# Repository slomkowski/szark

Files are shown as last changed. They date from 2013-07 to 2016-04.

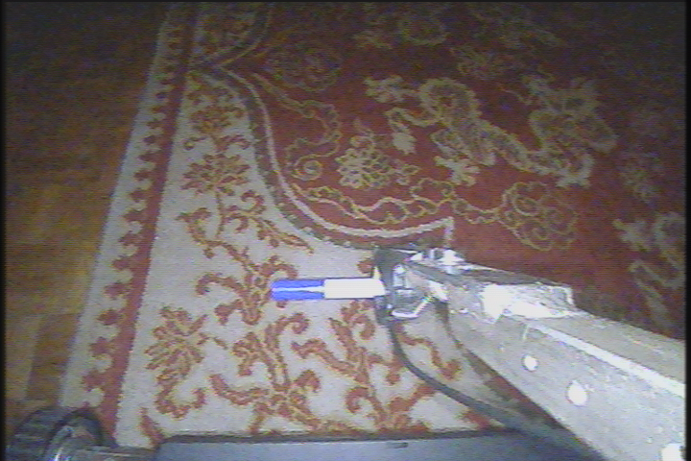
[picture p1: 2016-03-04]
server/camera_server/test_image.png

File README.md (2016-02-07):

# SZARK

Autonomic robot platform. Work in progress.

## Installation

Requred packages for Ubuntu:
```bash
apt-get install clang cmake git libboost-all-dev libjsoncpp-dev liblog4cpp5-dev libnl-genl-3-dev libnl-route-3-dev libopencv-dev libusb-1.0-0-dev libdw-dev 
```

Steps to clone the repository:
```bash
git clone https://github.com/slomkowski/szark.git
cd szark/
git submodule init
git submodule update
```

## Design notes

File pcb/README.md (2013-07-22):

SZARK - PCBs and schematics
===========================

&copy; 2011 - 2013 Michał Słomkowski GNU GPL v.3
https://github.com/slomkowski/szark

The files here are created in Cadsoft Eagle 6.x Light. You have to have this program installed to open them.

The project contains:
* **bridge** - interface between computer and other robot peripherals,
* **arm_driver**
* **motor_driver**
* **i2c_expander**
* **charger**
* **encoder**, **encoder_se**,**encoder_wrist** - various optical encoder designs installed on power motors and robotic arm.

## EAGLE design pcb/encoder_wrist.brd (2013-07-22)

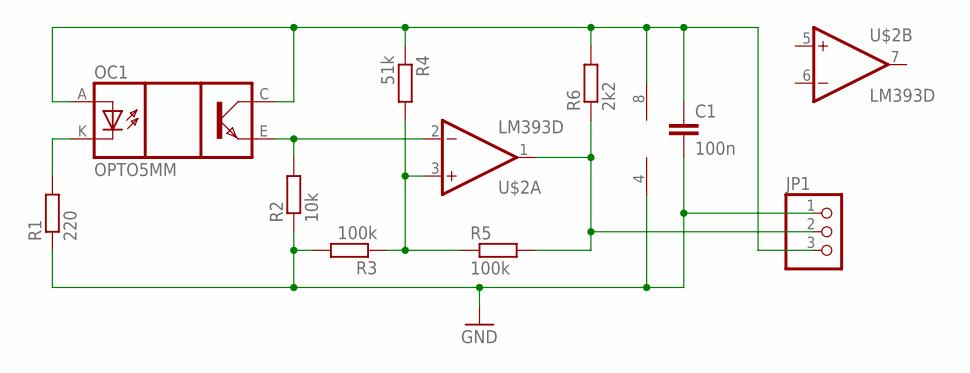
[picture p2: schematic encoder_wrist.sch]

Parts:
C1: 100n; C1206
JP1: PINHD-1X3/90; 1X03/90
OC1: OPTO5MM; OPTO_5MM
R1: 220; M1206
R2: 10k; M1206
R3, R5: 100k; M1206
R4: 51k; M1206
R6: 2k2; M1206
U$2: LM393D; SO08

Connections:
GND: C1.2, JP1.1, R1.1, R2.1, R3.2, U$2.4 (V-)
unnamed: OC1.K (C), R1.2
unnamed: R3.1, R4.2, R5.1, U$2.3 (+IN)
unnamed: JP1.2, R5.2, R6.1, U$2.1 (OUT)
unnamed: OC1.E (EMIT), R2.2, U$2.2 (-IN)
unnamed: C1.1, JP1.3, OC1.A, OC1.C (COL), R4.1, R6.2, U$2.8 (V+)

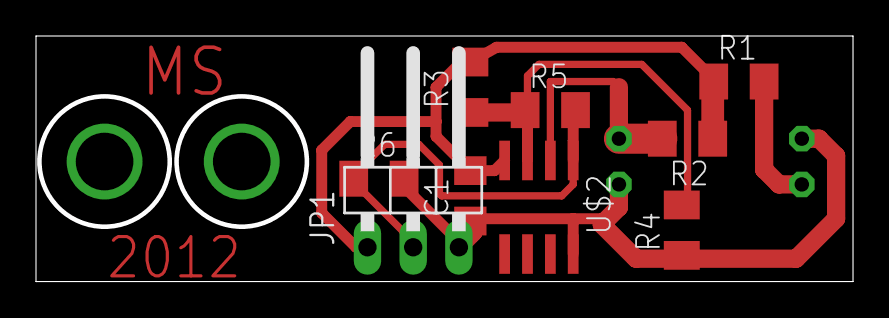
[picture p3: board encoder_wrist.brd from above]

Board: 2 copper layers, 45.4 x 13.6 mm, 10 parts (1 on the bottom side), 6 nets.

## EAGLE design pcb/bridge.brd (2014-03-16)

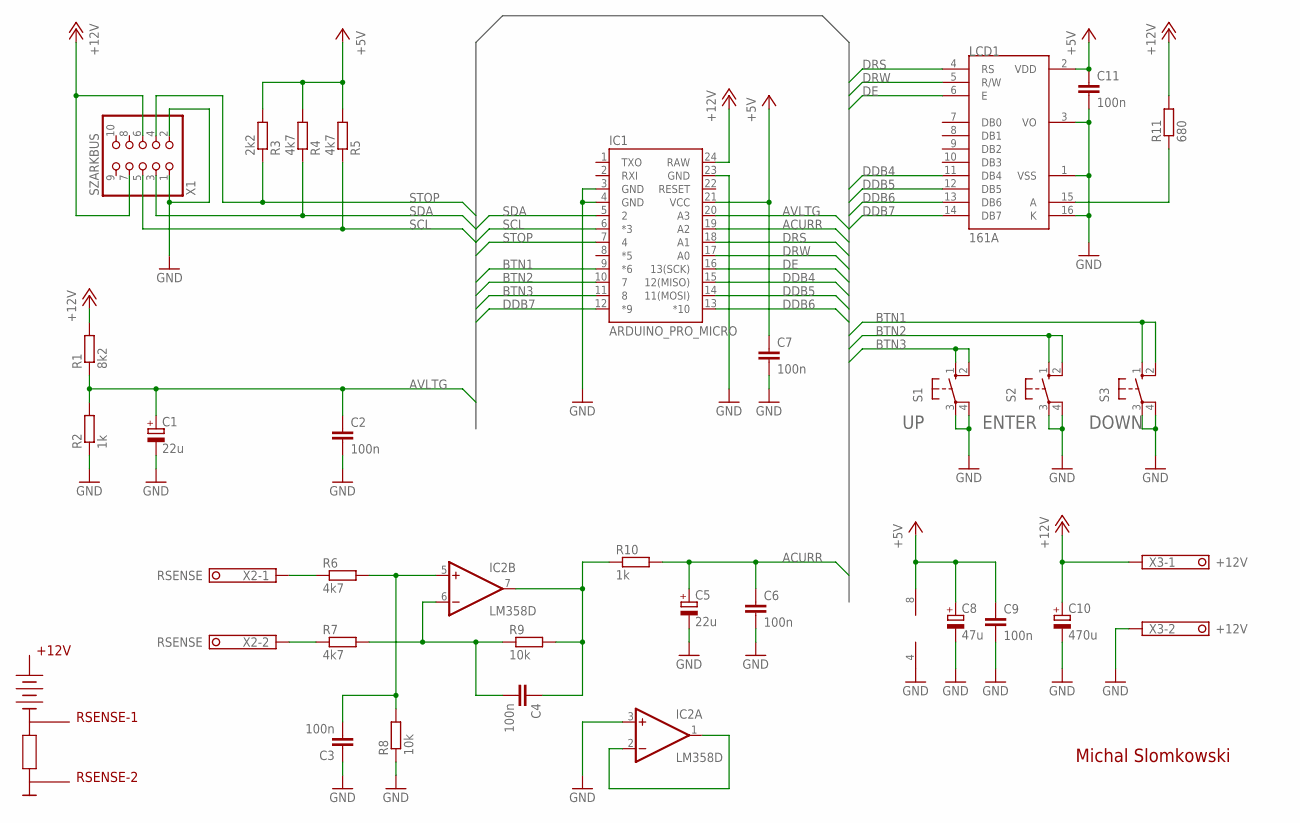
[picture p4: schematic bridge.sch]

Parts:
C1, C5: 22u; B/3528-21W
C2, C4, C6, C7, C9, C11: 100n; C1206
C3: 100n; C1210
C8: 47u; C/6032-28W
C10: 470u; E5-8,5
IC1: ARDUINO_PRO_MICRO
IC2: LM358D; SO08
LCD1: 161A
R1: 8k2; M1206
R2, R10: 1k; M1206
R3: 2k2; M1206
R4, R5, R6, R7: 4k7; M1206
R8, R9: 10k; M1206
R11: 680; 0207/12
S1, S2, S3: 10-XX; B3F-10XX
X1: SZARKBUS; 2X05
X2: RSENSE; 1751248
X3: +12V; 1751248

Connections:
+5V: C7.1, C8.+, C9.1, C11.1, IC1.21 (VCC), IC2.8 (V+), LCD1.2 (VDD), R3.2, R4.2, R5.2
+12V: C10.+, IC1.24 (RAW), R1.2, R11.2, X1.6, X1.7, X3.1
ACURR: C5.+, C6.1, IC1.19 (A2), R10.2
AVLTG: C1.+, C2.1, IC1.20 (A3), R1.1, R2.2
BTN1: IC1.9 (*6), S3.1 (S), S3.2 (S1)
BTN2: IC1.10 (7), S2.1 (S), S2.2 (S1)
BTN3: IC1.11 (8), S1.1 (S), S1.2 (S1)
DDB4: IC1.15 (12(MISO)), LCD1.11 (DB4)
DDB5: IC1.14 (11(MOSI)), LCD1.12 (DB5)
DDB6: IC1.13 (*10), LCD1.13 (DB6)
DDB7: IC1.12 (*9), LCD1.14 (DB7)
DE: IC1.16 (13(SCK)), LCD1.6 (E)
DRS: IC1.18 (A1), LCD1.4 (RS)
DRW: IC1.17 (A0), LCD1.5 (R/W)
GND: C1.-, C2.2, C3.1, C5.-, C6.2, C7.2, C8.-, C9.2, C10.-, C11.2, IC1.3 (GND), IC1.4 (GND), IC1.23 (GND), IC2.3 (+IN), IC2.4 (V-), LCD1.1 (VSS), LCD1.3 (VO), LCD1.16 (K), R2.1, R8.1, S1.3, S1.4 (P1), S2.3, S2.4 (P1), S3.3, S3.4 (P1), X1.1, X1.2, X3.2
unnamed: C3.2, IC2.5 (+IN), R6.2, R8.2
unnamed: LCD1.15 (A), R11.1
unnamed: C4.2, IC2.6 (-IN), R7.2, R9.1
unnamed: IC2.1 (OUT), IC2.2 (-IN)
unnamed: R7.1, X2.2
unnamed: R6.1, X2.1
NET3: C4.1, IC2.7 (OUT), R9.2, R10.1
SCL: IC1.6 (*3), R5.1, X1.5
SDA: IC1.5 (2), R4.1, X1.3
STOP: IC1.7 (4), R3.1, X1.4

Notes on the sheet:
+12V
RSENSE-1
RSENSE-2
ENTER
DOWN
Michal Slomkowski

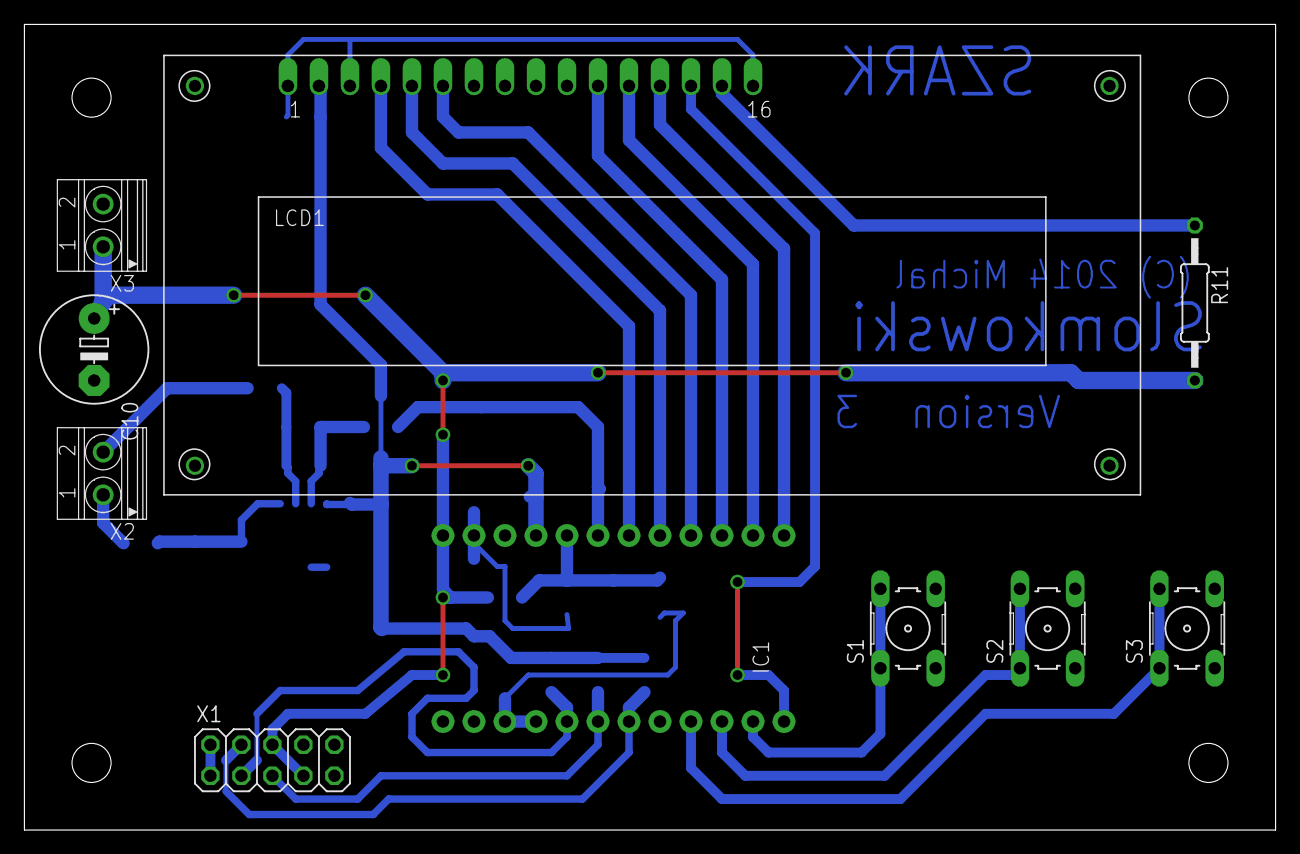
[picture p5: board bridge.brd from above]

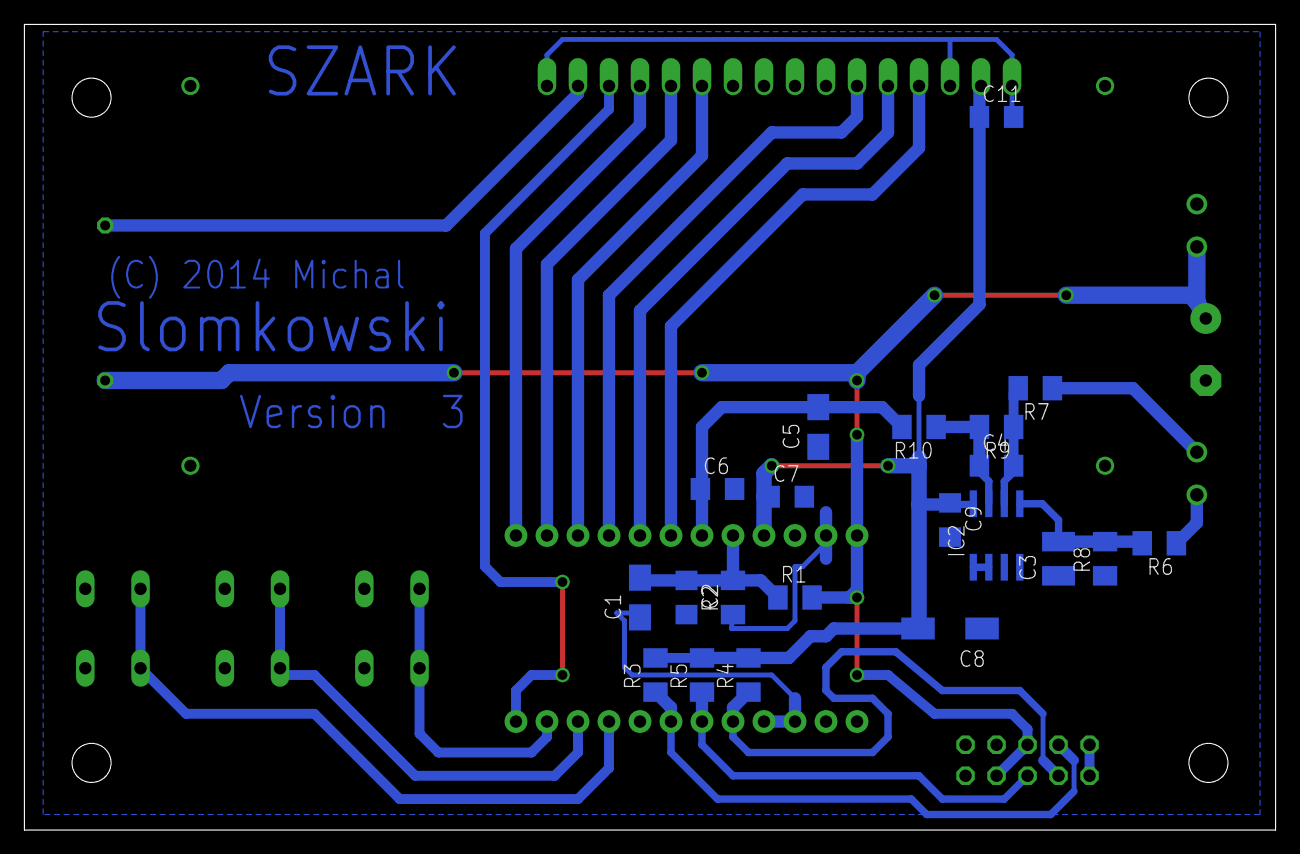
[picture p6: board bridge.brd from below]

Board: 2 copper layers, 102.5 x 66.0 mm, 31 parts (21 on the bottom side), 25 nets.

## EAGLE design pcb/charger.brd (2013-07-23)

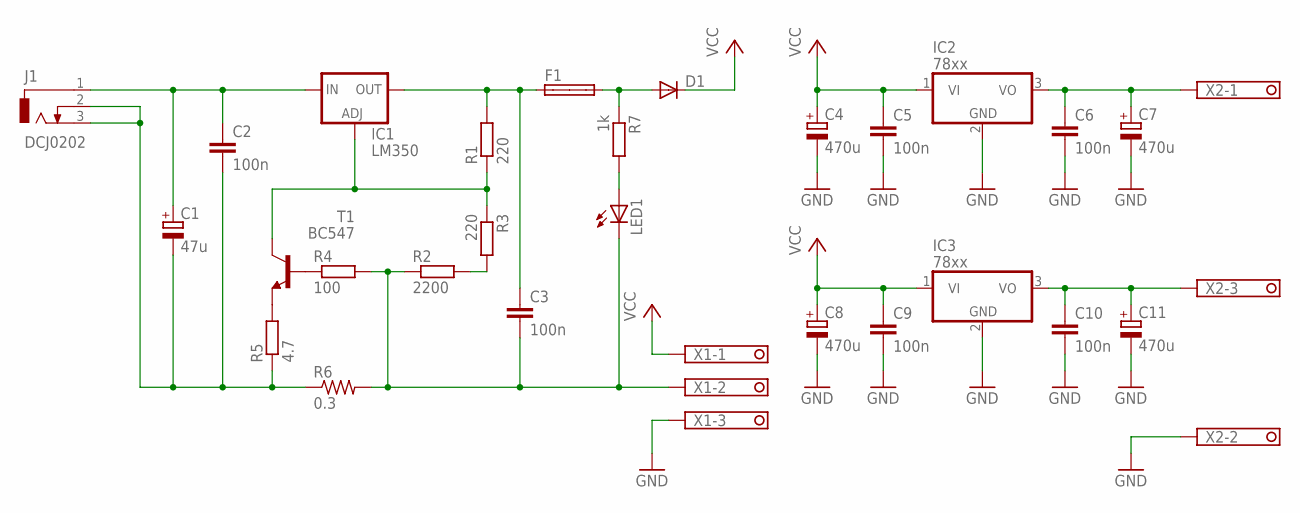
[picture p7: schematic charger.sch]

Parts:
C1: 47u; E2,5-7
C2, C3, C5, C6, C9, C10: 100n; C050-030X075
C4, C7, C8, C11: 470u; E5-10,5
D1: SB320; DO201-15
F1: SHK20L
IC1: LM350; 317TS
IC2, IC3: 78xx; TO220V
J1: DCJ0202
LED1: LED5MM
R1, R3: 220; 0207/10
R2: 2200; 0207/10
R4: 100; 0207/10
R5: 4.7; 0207/10
R6: 0.3; 0617/22
R7: 1k; 0207/10
T1: BC547; TO92
X1, X2: 1751251

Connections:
GND: C4.-, C5.2, C6.2, C7.-, C8.-, C9.2, C10.2, C11.-, IC2.2 (GND), IC3.2 (GND), X1.3, X2.2
unnamed: C1.+, C2.1, IC1.3 (IN), J1.1
unnamed: C1.-, C2.2, J1.2, J1.3, R5.1, R6.1
unnamed: R4.1, T1.2 (B)
unnamed: R2.2, R3.2
unnamed: IC1.1 (ADJ), R1.1, R3.1, T1.3 (C)
unnamed: C10.1, C11.+, IC3.3 (VO), X2.3
unnamed: C3.2, LED1.K (C), R2.1, R4.2, R6.2, X1.2
unnamed: R5.2, T1.1 (E)
unnamed: D1.A, F1.2A, R7.1
unnamed: LED1.A, R7.2
unnamed: C6.1, C7.+, IC2.3 (VO), X2.1
unnamed: C3.1, F1.1A, IC1.2 (OUT), R1.2
VCC: C4.+, C5.1, C8.+, C9.1, D1.C, IC2.1 (VI), IC3.1 (VI), X1.1

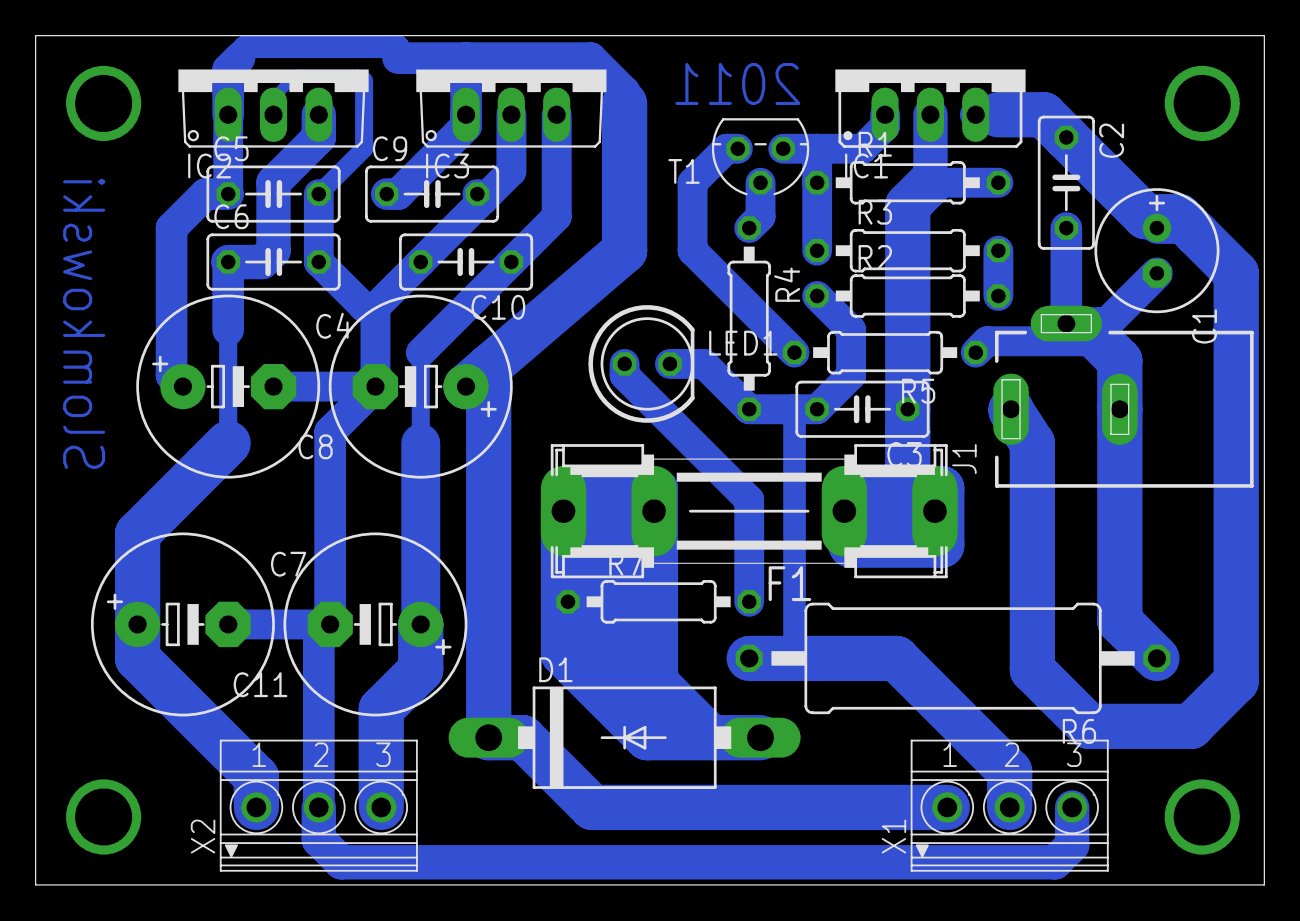
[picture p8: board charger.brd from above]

Board: 2 copper layers, 68.9 x 47.6 mm, 28 parts (0 on the bottom side), 14 nets.

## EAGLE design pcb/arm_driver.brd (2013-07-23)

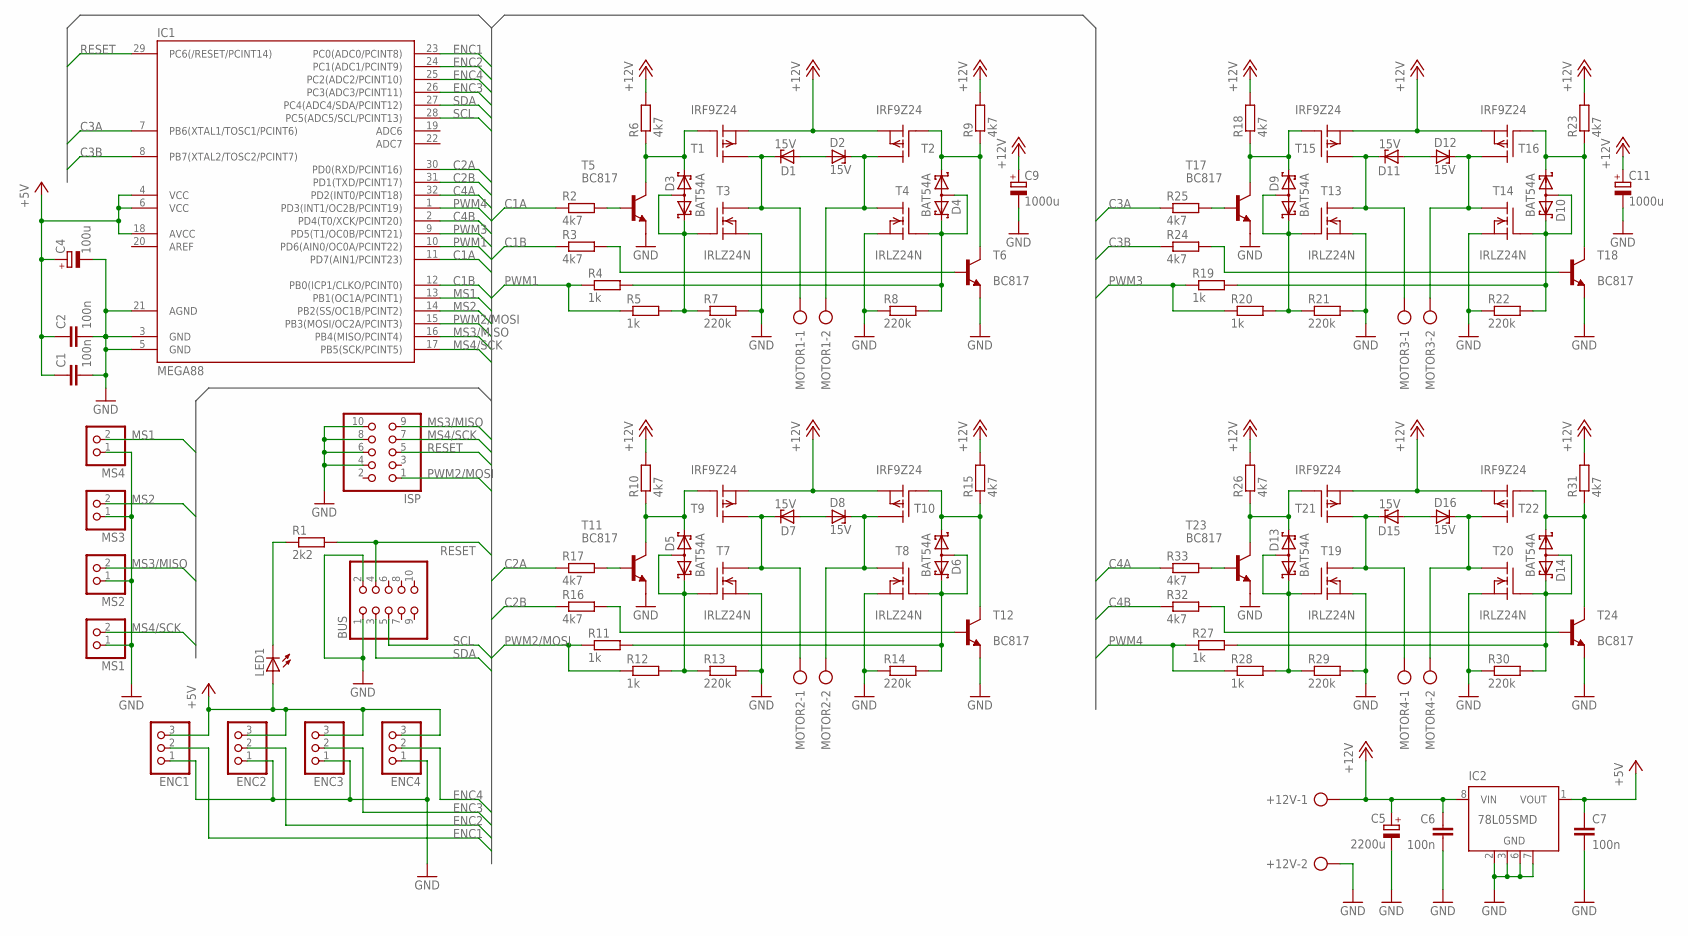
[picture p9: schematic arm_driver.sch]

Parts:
+12V: AK500/2
BUS: PINHD-2X5; 2X05
C1, C2, C6, C7: 100n; C1206
C4: 100u; D/7343-31R
C5: 2200u; E7,5-16
C9, C11: 1000u; E5-13
D1, D2, D7, D8, D11, D12, D15, D16: 15V; SOD80C
D3, D4, D5, D6, D9, D10, D13, D14: BAT54A; SOT23
ENC1, ENC2, ENC3, ENC4: PINHD-1X3; 1X03
IC1: MEGA88; TQFP32-08
IC2: 78L05SMD; SO08
ISP: PINHD-2X5; 2X05
LED1: LEDKA-3528ASYC; KA-3528ASYC
MOTOR1, MOTOR2, MOTOR3, MOTOR4: AK500/2
MS1, MS2, MS3, MS4: PINHD-1X2; 1X02
R1: 2k2; R1206
R2, R3, R6, R9, R10, R15, R16, R17, R18, R23, R24, R25, R26, R31, R32, R33: 4k7; R1206
R4, R5, R11, R12, R19, R20, R27, R28: 1k; R1206
R7, R8, R13, R14, R21, R22, R29, R30: 220k; R1206
T1, T2, T9, T10, T15, T16, T21, T22: IRF9Z24; TO220
T3, T4, T7, T8, T13, T14, T19, T20: IRLZ24N; TO220
T5, T6, T11, T12, T17, T18, T23, T24: BC817; SOT23-BEC

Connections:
+5V: C1.1, C2.1, C4.+, C7.1, ENC1.3, ENC2.3, ENC3.3, ENC4.3, IC1.4 (VCC), IC1.6 (VCC), IC1.18 (AVCC), IC2.1 (VOUT), LED1.A
+12V: +12V.1, C5.+, C6.1, C9.+, C11.+, IC2.8 (VIN), R6.2, R9.2, R10.2, R15.2, R18.2, R23.2, R26.2, R31.2, T1.3 (S), T2.3 (S), T9.3 (S), T10.3 (S), T15.3 (S), T16.3 (S), T21.3 (S), T22.3 (S)
C1A: IC1.11 (PD7(AIN1/PCINT23)), R2.1
C1B: IC1.12 (PB0(ICP1/CLKO/PCINT0)), R3.1
C2A: IC1.30 (PD0(RXD/PCINT16)), R17.1
C2B: IC1.31 (PD1(TXD/PCINT17)), R16.1
C3A: IC1.7 (PB6(XTAL1/TOSC1/PCINT6)), R25.1
C3B: IC1.8 (PB7(XTAL2/TOSC2/PCINT7)), R24.1
C4A: IC1.32 (PD2(INT0/PCINT18)), R33.1
C4B: IC1.2 (PD4(T0/XCK/PCINT20)), R32.1
ENC1: ENC1.2, IC1.23 (PC0(ADC0/PCINT8))
ENC2: ENC2.2, IC1.24 (PC1(ADC1/PCINT9))
ENC3: ENC3.2, IC1.26 (PC3(ADC3/PCINT11))
ENC4: ENC4.2, IC1.25 (PC2(ADC2/PCINT10))
GND: +12V.2, BUS.1, BUS.2, C1.2, C2.2, C4.-, C5.-, C6.2, C7.2, C9.-, C11.-, ENC1.1, ENC2.1, ENC3.1, ENC4.1, IC1.3 (GND), IC1.5 (GND), IC1.21 (AGND), IC2.2 (GND), IC2.3 (GND), IC2.6 (GND), IC2.7 (GND), ISP.4, ISP.6, ISP.8, ISP.10, MS1.1, MS2.1, MS3.1, MS4.1, R7.2, R8.1, R13.2, R14.1, R21.2, R22.1, R29.2, R30.1, T3.3 (S), T4.3 (S), T5.E, T6.E, T7.3 (S), T8.3 (S), T11.E, T12.E, T13.3 (S), T14.3 (S), T17.E, T18.E, T19.3 (S), T20.3 (S), T23.E, T24.E
MS1: IC1.13 (PB1(OC1A/PCINT1)), MS4.2
MS2: IC1.14 (PB2(SS/OC1B/PCINT2)), MS3.2
MS3/MISO: IC1.16 (PB4(MISO/PCINT4)), ISP.9, MS2.2
MS4/SCK: IC1.17 (PB5(SCK/PCINT5)), ISP.7, MS1.2
unnamed: LED1.C, R1.1
unnamed: D2.C, MOTOR1.2, T2.2 (D), T4.2 (D)
unnamed: D1.A, D2.A
unnamed: D3.2 (K2), R6.1, T1.1 (G), T5.C
unnamed: D4.1 (K1), R9.1, T2.1 (G), T6.C
unnamed: D4.2 (K2), D4.3 (AA), R4.2, R8.2, T4.1 (G)
unnamed: R3.2, T6.B
unnamed: R2.2, T5.B
unnamed: D3.1 (K1), D3.3 (AA), R5.2, R7.1, T3.1 (G)
unnamed: D1.C, MOTOR1.1, T1.2 (D), T3.2 (D)
unnamed: D7.C, MOTOR2.1, T7.2 (D), T9.2 (D)
unnamed: D8.C, MOTOR2.2, T8.2 (D), T10.2 (D)
unnamed: D5.2 (K2), R10.1, T9.1 (G), T11.C
unnamed: D6.1 (K1), R15.1, T10.1 (G), T12.C
unnamed: D6.2 (K2), D6.3 (AA), R11.2, R14.2, T8.1 (G)
unnamed: D5.1 (K1), D5.3 (AA), R12.2, R13.1, T7.1 (G)
unnamed: D7.A, D8.A
unnamed: R16.2, T12.B
unnamed: R17.2, T11.B
unnamed: D11.C, MOTOR3.1, T13.2 (D), T15.2 (D)
unnamed: D12.C, MOTOR3.2, T14.2 (D), T16.2 (D)
unnamed: D9.2 (K2), R18.1, T15.1 (G), T17.C
unnamed: D10.1 (K1), R23.1, T16.1 (G), T18.C
unnamed: D10.2 (K2), D10.3 (AA), R19.2, R22.2, T14.1 (G)
unnamed: D9.1 (K1), D9.3 (AA), R20.2, R21.1, T13.1 (G)
unnamed: D11.A, D12.A
unnamed: R24.2, T18.B
unnamed: R25.2, T17.B
unnamed: D15.C, MOTOR4.1, T19.2 (D), T21.2 (D)
unnamed: D16.C, MOTOR4.2, T20.2 (D), T22.2 (D)
unnamed: D13.2 (K2), R26.1, T21.1 (G), T23.C
unnamed: D14.1 (K1), R31.1, T22.1 (G), T24.C
unnamed: D14.2 (K2), D14.3 (AA), R27.2, R30.2, T20.1 (G)
unnamed: D13.1 (K1), D13.3 (AA), R28.2, R29.1, T19.1 (G)
unnamed: D15.A, D16.A
unnamed: R32.2, T24.B
unnamed: R33.2, T23.B
PWM1: IC1.10 (PD6(AIN0/OC0A/PCINT22)), R4.1, R5.1
PWM2/MOSI: IC1.15 (PB3(MOSI/OC2A/PCINT3)), ISP.1, R11.1, R12.1
PWM3: IC1.9 (PD5(T1/OC0B/PCINT21)), R19.1, R20.1
PWM4: IC1.1 (PD3(INT1/OC2B/PCINT19)), R27.1, R28.1
RESET: BUS.4, IC1.29 (PC6(/RESET/PCINT14)), ISP.5, R1.2
SCL: BUS.5, IC1.28 (PC5(ADC5/SCL/PCINT13))
SDA: BUS.3, IC1.27 (PC4(ADC4/SDA/PCINT12))

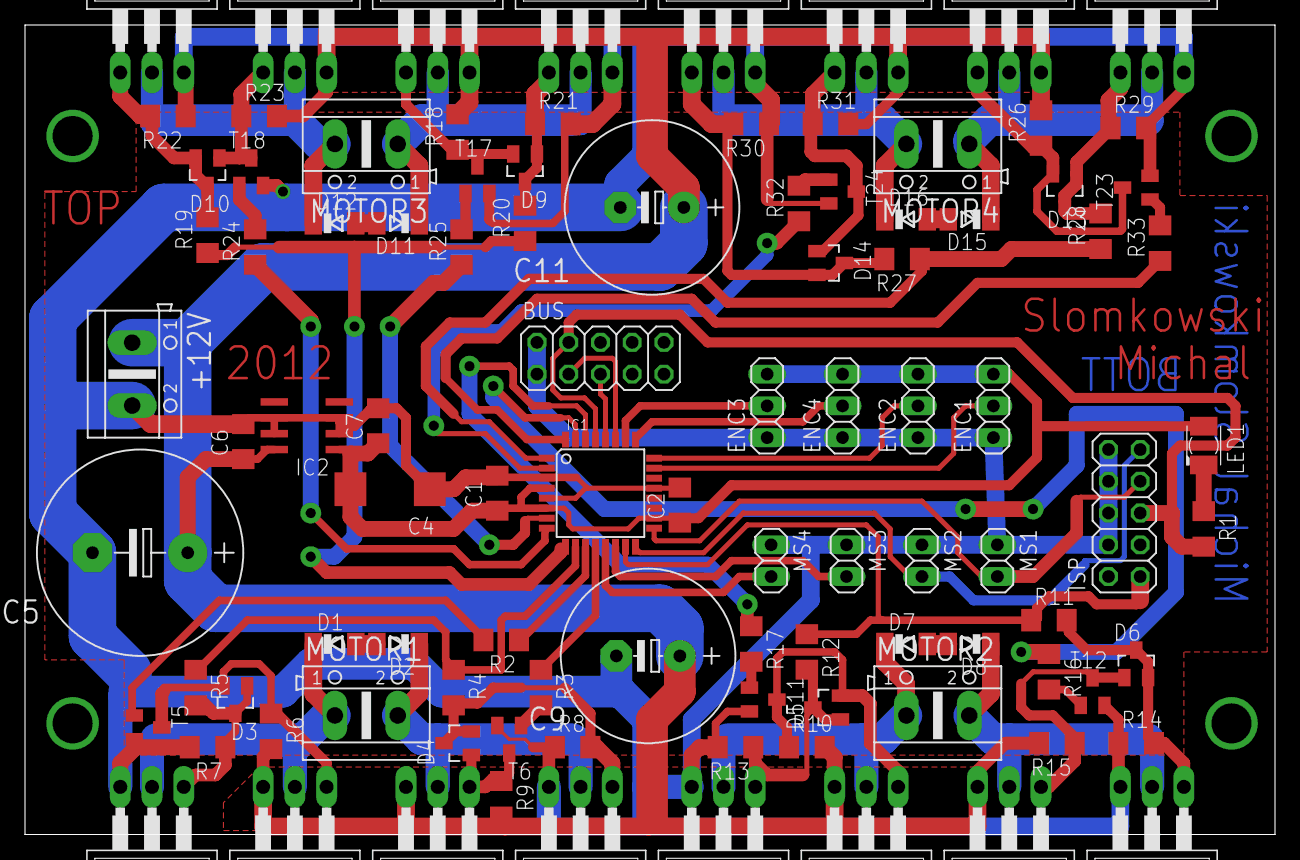
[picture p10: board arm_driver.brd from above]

Board: 2 copper layers, 100.0 x 64.8 mm, 99 parts (0 on the bottom side), 63 nets.

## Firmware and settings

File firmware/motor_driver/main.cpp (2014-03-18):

/*
 #  SZARK - Sterowana Zdalnie lub Autonomicznie Rozwojowa Konstrukcja
 #  Michał Słomkowski 2011
 #  www.flylab.ovh.org m.slomkowski@gmail.com
 */

// main module
#include "global.hpp"

#include <avr/io.h>
#include <avr/interrupt.h>
#include <avr/wdt.h>

#include "motor.hpp"
#include "i2c-slave.hpp"

int main() {
#if DEBUG
	// debug pin set to output
	DDR(DEBUG_PORT) |= (1 << DEBUG_PIN);
#endif

	motor::init();
	i2c_initialize((I2C_SLAVE_ADDRESS << 1));

	sei();

	// Watchdog
#if !DEBUG
	wdt_enable(WDTO_120MS);
#endif

	while (1) {
		// generic
		if (i2c_reply_ready()) {
			motor::Motor motor = (motor::Motor) i2c_wrbuf[1];

			if (i2c_wrbuf[0] == motor::GET_SPEED) {
				i2c_rdbuf[0] = motor::getSpeed(motor);
			} else {
				i2c_rdbuf[0] = motor::getDirection(motor);
			}

			i2c_reply_done(1);
		}

		if (i2c_message_ready()) {
			motor::Motor motor = (motor::Motor) i2c_wrbuf[1];

			switch (i2c_wrbuf[0]) {
			case motor::BRAKE:
				motor::setDirection(motor::MOTOR1, motor::STOP);
				motor::setDirection(motor::MOTOR2, motor::STOP);
				break;
			case motor::SET_SPEED:
				motor::setSpeed(motor, i2c_wrbuf[2]);
				break;
			case motor::SET_DIRECTION:
				motor::setDirection(motor, (motor::Direction) i2c_wrbuf[2]);
				break;

			};
			i2c_message_done();
		}

#if !DEBUG
		wdt_reset();
#endif
	}
}

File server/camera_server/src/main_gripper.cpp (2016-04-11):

#define BACKWARD_HAS_DW 1

#include "IoServiceProvider.hpp"
#include "initialization.hpp"

#include <backward.hpp>
#include <wallaroo/catalog.h>

using namespace std;
using namespace wallaroo;

int main(int argc, char *argv[]) {
    backward::SignalHandling sh;

    const char *banner = "SZARK Camera Server\n(C) Michał Słomkowski\nCompilation: " __DATE__;

    auto configFiles = common::init::initializeProgram(argc, argv, banner);

    Catalog c;
    c.Create("conf", "Configuration", configFiles);
    c.Create("imgGrabberLeft", "Video4LinuxImageGrabber", string("left"));
    c.Create("imgGrabberRight", "Video4LinuxImageGrabber", string("right"));
    c.Create("ifaceProvider", "InterfaceProvider", false);
    c.Create("imgCombiner", "GripperImageSource");
    c.Create("hudPainter", "GripperHudPainter");
    c.Create("ioServiceProvider", "IoServiceProvider");
    c.Create("srv", "NetworkServer");
    c.Create("jpegEncoder", "OpenCvJpegEncoder");

    wallaroo_within(c) {
        use("conf").as("config").of("imgGrabberLeft");
        use("conf").as("config").of("imgGrabberRight");
        use("conf").as("config").of("imgCombiner");
        use("conf").as("config").of("hudPainter");
        use("conf").as("config").of("srv");

        use("ioServiceProvider").as("ioServiceProvider").of("srv");
        use("imgGrabberLeft").as("leftCameraGrabber").of("imgCombiner");
        use("imgGrabberRight").as("rightCameraGrabber").of("imgCombiner");
        use("hudPainter").as("hudPainter").of("imgCombiner");
        use("imgCombiner").as("imageSource").of("srv");
        use("jpegEncoder").as("jpegEncoder").of("srv");
    };

    c.CheckWiring();
    c.Init();

    std::shared_ptr<common::IoServiceProvider>(c["ioServiceProvider"])->run();

    return 0;
}

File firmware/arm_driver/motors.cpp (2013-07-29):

#include "global.h"

#include <avr/io.h>
#include <inttypes.h>
#include <avr/interrupt.h>
#include <util/delay.h>

#include "motors.h"

// mode of operation - DIR, POS, CAL - global
volatile bool calibrated __attribute__ ((section (".noinit")));
volatile bool interruptCalibration, startCalibration;

#define getval(sfr, bit) (bit_is_set(sfr, bit) ? true : false)

// this struct stores the values for single joint
static volatile struct {
	// position
	POSITION currPos; // current position
	POSITION destPos; // desired position
	POSITION maxPos;  // maximal position

	// direction
	DIRECTION allowedDir;
	DIRECTION currDir;

	// speed
	SPEED currSpeed;
	SPEED initSpeed;

	// calibration
	bool calibrated;
	MODE mode;

	// MS parameters
	uint8_t msCounter;bool msCurrState; // false - low, true - high

	// encoders
	bool encoderState;bool prevEncoderState;
} joints[4] __attribute__ ((section (".noinit")));

// these values index the 'joints' table.
typedef enum {
	SHOULDER = 0, ELBOW, GRIPPER, WRIST
} JOINT_INDEX;

//*** local functions
static JOINT_INDEX toJoint(MOTOR motor);
static MOTOR toMotors(JOINT_INDEX index);
static MOTOR toMotors(uint8_t index);
static void setTimerMs(uint16_t interval); // in milliseconds
static void setTimerContinuous();
static bool getMsState(JOINT_INDEX index);
static bool getMsState(uint8_t index);

static volatile bool timerNotClear = true, timerOneShot = true;

//*** basic getters

SPEED motor_get_speed(MOTOR motor) {
	return joints[toJoint(motor)].currSpeed;
}

DIRECTION motor_get_direction(MOTOR motor) {
	return joints[toJoint(motor)].currDir;
}

POSITION motor_get_position(MOTOR motor) {
	return joints[toJoint(motor)].currPos;
}

MODE motor_get_mode(MOTOR motor) {
	return joints[toJoint(motor)].mode;
}

// basic setters. The setters put the data in the structure and send the data to the appropriate output (registers, pins)

void motor_set_speed(MOTOR motor, SPEED speed) {
	// put data to the struct
	joints[toJoint(motor)].currSpeed = speed;

	// put it to the registers
	switch (motor) {
	case MOTOR_SHOULDER:
		PWM_SHOULDER_REG = speed << 4;
		break;
	case MOTOR_ELBOW:
		PWM_ELBOW_REG = speed << 4;
		break;
	case MOTOR_WRIST:
		PWM_WRIST_REG = speed << 4;
		break;
	case MOTOR_GRIPPER:
		PWM_GRIPPER_REG = speed << 4;
		break;
	};
}

void motor_set_direction(MOTOR motor, DIRECTION direction) {
	DIRECTION currentDir;
	const JOINT_INDEX idx = toJoint(motor);

	if (joints[idx].mode == POS) joints[idx].mode = DIR;

	// put data to the struct, checking if the command is
	if ((((direction == MOTOR_FORWARD) || (direction == MOTOR_BACKWARD)) && (joints[idx].allowedDir == MOTOR_NONE)
		|| (joints[idx].allowedDir == direction))) joints[idx].currDir = direction;

	else joints[idx].currDir = MOTOR_STOP;

	currentDir = joints[idx].currDir;

	// put them to the output
	switch (motor) {
	case MOTOR_SHOULDER:
		if (currentDir == MOTOR_FORWARD) {
			PORT(MOTOR_SHOULDER_FORWARD_PORT) |= (1 << MOTOR_SHOULDER_FORWARD_PIN);
			PORT(MOTOR_SHOULDER_BACKWARD_PORT) &= ~(1 << MOTOR_SHOULDER_BACKWARD_PIN);
		} else if (currentDir == MOTOR_BACKWARD) {
			PORT(MOTOR_SHOULDER_FORWARD_PORT) &= ~(1 << MOTOR_SHOULDER_FORWARD_PIN);
			PORT(MOTOR_SHOULDER_BACKWARD_PORT) |= (1 << MOTOR_SHOULDER_BACKWARD_PIN);
		} else {
			// braking
			PORT(MOTOR_SHOULDER_FORWARD_PORT) |= (1 << MOTOR_SHOULDER_FORWARD_PIN);
			PORT(MOTOR_SHOULDER_BACKWARD_PORT) |= (1 << MOTOR_SHOULDER_BACKWARD_PIN);
		}
		break;
	case MOTOR_ELBOW:
		if (currentDir == MOTOR_FORWARD) {
			PORT(MOTOR_ELBOW_FORWARD_PORT) |= (1 << MOTOR_ELBOW_FORWARD_PIN);
			PORT(MOTOR_ELBOW_BACKWARD_PORT) &= ~(1 << MOTOR_ELBOW_BACKWARD_PIN);

		} else if (currentDir == MOTOR_BACKWARD) {
			PORT(MOTOR_ELBOW_FORWARD_PORT) &= ~(1 << MOTOR_ELBOW_FORWARD_PIN);
			PORT(MOTOR_ELBOW_BACKWARD_PORT) |= (1 << MOTOR_ELBOW_BACKWARD_PIN);
		} else {
			PORT(MOTOR_ELBOW_FORWARD_PORT) |= (1 << MOTOR_ELBOW_FORWARD_PIN);
			PORT(MOTOR_ELBOW_BACKWARD_PORT) |= (1 << MOTOR_ELBOW_BACKWARD_PIN);
		}
		break;
	case MOTOR_WRIST:
		if (currentDir == MOTOR_FORWARD) {
			PORT(MOTOR_WRIST_FORWARD_PORT) |= (1 << MOTOR_WRIST_FORWARD_PIN);
			PORT(MOTOR_WRIST_BACKWARD_PORT) &= ~(1 << MOTOR_WRIST_BACKWARD_PIN);

		} else if (currentDir == MOTOR_BACKWARD) {
			PORT(MOTOR_WRIST_FORWARD_PORT) &= ~(1 << MOTOR_WRIST_FORWARD_PIN);
			PORT(MOTOR_WRIST_BACKWARD_PORT) |= (1 << MOTOR_WRIST_BACKWARD_PIN);
		} else {
			PORT(MOTOR_WRIST_FORWARD_PORT) |= (1 << MOTOR_WRIST_FORWARD_PIN);
			PORT(MOTOR_WRIST_BACKWARD_PORT) |= (1 << MOTOR_WRIST_BACKWARD_PIN);
		}
		break;
	case MOTOR_GRIPPER:
		if (currentDir == MOTOR_FORWARD) {
			PORT(MOTOR_GRIPPER_FORWARD_PORT) |= (1 << MOTOR_GRIPPER_FORWARD_PIN);
			PORT(MOTOR_GRIPPER_BACKWARD_PORT) &= ~(1 << MOTOR_GRIPPER_BACKWARD_PIN);

		} else if (currentDir == MOTOR_BACKWARD) {
			PORT(MOTOR_GRIPPER_FORWARD_PORT) &= ~(1 << MOTOR_GRIPPER_FORWARD_PIN);
			PORT(MOTOR_GRIPPER_BACKWARD_PORT) |= (1 << MOTOR_GRIPPER_BACKWARD_PIN);
		} else {
			PORT(MOTOR_GRIPPER_FORWARD_PORT) |= (1 << MOTOR_GRIPPER_FORWARD_PIN);
			PORT(MOTOR_GRIPPER_BACKWARD_PORT) |= (1 << MOTOR_GRIPPER_BACKWARD_PIN);
		}
		break;
	};
}

void motor_set_position(MOTOR motor, POSITION position) {
	const JOINT_INDEX idx = toJoint(motor);

	if (joints[idx].calibrated == false) return;
	if (joints[idx].maxPos < position) return;

	if ((idx == GRIPPER) && (position > 0)) position = joints[GRIPPER].maxPos;

	joints[idx].destPos = position;

	if (joints[idx].currPos < position) {
		motor_set_direction(motor, MOTOR_FORWARD);
		joints[idx].mode = POS;
	} else if (joints[idx].currPos > position) {
		motor_set_direction(motor, MOTOR_BACKWARD);
		joints[idx].mode = POS;
	} else // if equal
	{
		motor_set_direction(motor, MOTOR_STOP);
		joints[idx].mode = DIR;
	}
}

void motor_brake() {
	uint8_t i;
	// instantly brake all the motors
	for (i = 0; i < 4; i++) {
		motor_set_speed(toMotors(i), 0);
		motor_set_direction(toMotors(i), MOTOR_STOP);
	}
}

//*** init functions
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

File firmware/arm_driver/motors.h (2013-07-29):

#ifndef _MOTORS_H_
#define _MOTORS_H_

#include <inttypes.h>

#include "global.h"
#include "arm_driver-commands.h"


//*** I/O configuration - bound to hardware

// output pins
#define MOTOR_GRIPPER_PWM_PORT D
#define MOTOR_GRIPPER_PWM_PIN 6
#define MOTOR_GRIPPER_FORWARD_PORT B
#define MOTOR_GRIPPER_FORWARD_PIN 0
#define MOTOR_GRIPPER_BACKWARD_PORT D
#define MOTOR_GRIPPER_BACKWARD_PIN 7

#define MOTOR_SHOULDER_PWM_PORT B
#define MOTOR_SHOULDER_PWM_PIN 3
#define MOTOR_SHOULDER_FORWARD_PORT D
#define MOTOR_SHOULDER_FORWARD_PIN 0
#define MOTOR_SHOULDER_BACKWARD_PORT D
#define MOTOR_SHOULDER_BACKWARD_PIN 1

#define MOTOR_WRIST_PWM_PORT D
#define MOTOR_WRIST_PWM_PIN 5
#define MOTOR_WRIST_FORWARD_PORT B
#define MOTOR_WRIST_FORWARD_PIN 6
#define MOTOR_WRIST_BACKWARD_PORT B
#define MOTOR_WRIST_BACKWARD_PIN 7

#define MOTOR_ELBOW_PWM_PORT D
#define MOTOR_ELBOW_PWM_PIN 3
#define MOTOR_ELBOW_FORWARD_PORT D
#define MOTOR_ELBOW_FORWARD_PIN 2
#define MOTOR_ELBOW_BACKWARD_PORT D
#define MOTOR_ELBOW_BACKWARD_PIN 4

#define PWM_GRIPPER_REG OCR0A
#define PWM_WRIST_REG OCR0B
#define PWM_SHOULDER_REG OCR2A
#define PWM_ELBOW_REG  OCR2B

// sensors
#define SENSOR_SHOULDER_ENC_PORT C
#define SENSOR_SHOULDER_ENC_PIN 0
#define SENSOR_SHOULDER_MS_PORT B
#define SENSOR_SHOULDER_MS_PIN 5

#define SENSOR_ELBOW_ENC_PORT C
#define SENSOR_ELBOW_ENC_PIN 1
#define SENSOR_ELBOW_MS_PORT B
#define SENSOR_ELBOW_MS_PIN 4

#define SENSOR_WRIST_ENC_PORT C
#define SENSOR_WRIST_ENC_PIN 2
#define SENSOR_WRIST_MS_PORT B
#define SENSOR_WRIST_MS_PIN 2

#define SENSOR_GRIPPER_ENC_PORT C
#define SENSOR_GRIPPER_ENC_PIN 3
#define SENSOR_GRIPPER_MS_PORT B
#define SENSOR_GRIPPER_MS_PIN 1

#define ENCODERS_PCMSK PCMSK1
#define SHOULDER_ENC_PCINT PCINT8
#define ELBOW_ENC_PCINT PCINT9
#define WRIST_ENC_PCINT PCINT10
#define GRIPPER_ENC_PCINT PCINT11

#define MS_PCMSK PCMSK0
#define SHOULDER_MS_PCINT PCINT5
#define ELBOW_MS_PCINT PCINT4
#define WRIST_MS_PCINT PCINT2
#define GRIPPER_MS_PCINT PCINT1

#define ENCODERS_INTERRUPT PCINT1_vect
#define MS_INTERRUPT PCINT0_vect

//*** initial speed settings - range 0 - 15
#define CAL_SPEED_SHOULDER	220
#define CAL_SPEED_ELBOW		100
#define CAL_SPEED_WRIST		100
#define CAL_SPEED_GRIPPER	15

#define POS_MAX_SHOULDER	79
#define POS_MAX_ELBOW	105
#define POS_MAX_WRIST	95
#define POS_MAX_GRIPPER	255

#define MS_DEBOUNCE_TIME 10 // ms
#define TIMER_MS_INTERVAL 2 // ms

#define MS_DEBOUNCE_COUNTER (MS_DEBOUNCE_TIME / TIMER_MS_INTERVAL)

//*** type definitions
typedef uint8_t POSITION;
typedef uint8_t SPEED;
// typedef DIRECTION - definition is in command-chars.h

typedef enum { DIR = 'D', POS = 'P', CAL = 'C' } MODE;
extern volatile bool startCalibration;
extern volatile bool calibrated __attribute__ ((section (".noinit")));
extern volatile bool interruptCalibration;

//*** getters
SPEED motor_get_speed(MOTOR motor);
DIRECTION motor_get_direction(MOTOR motor);
POSITION motor_get_position(MOTOR motor);
MODE motor_get_mode(MOTOR motor);

//*** setters
void motor_set_speed(MOTOR motor, SPEED speed);
void motor_set_direction(MOTOR motor, DIRECTION direction);
void motor_set_position(MOTOR motor, POSITION position);

//*** additional functions
void motor_calibrate();
void motor_brake();
void motor_init();


#endif

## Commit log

2013-07-16 Motor driver project added.
2013-07-17 Arm driver: removed UART, formatted all code to K&R, extracted speed controller to controller.c, playing around with PID.
2013-07-18 Motor_driver converted to C++.
2013-07-21 Displaying speed in motor driver menu.
2013-07-21 Added average speed array to the motor_driver. Made PWM module more C++-like, grouped variables into struct.
2013-07-22 PCB boards and schematics upload.
    [arm_driver.brd, arm_driver.sch, bridge.brd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]
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2013-07-23 Added fixed drive to motor driver.
    [motor.cpp, motor.h]
2013-07-23 Bridge USB schematic.
    [arm_driver.brd, arm_driver.sch, bridge.brd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]
2013-07-28 Bridge board ready.
    [bridge.brd, bridge.sch]
2013-07-28 Changed bridge board.
    [bridge.brd, bridge.sch]
2013-07-29 Fix name 'callibrate' to 'calibrate'
    [main.cpp]
2013-07-30 Motor_driver created enums in common/motor_driver-commands.h
2013-07-30 Adjusted bridge to use new enum interface for motor and arm.
2013-07-30 Motor_driver fixed error with not working controller.
    [controller.cpp, motor.cpp]
2013-07-31 arm_driver increased calibrate speed for elbow.
2013-08-05 bridge: Added I2C driver and part of motor_driver.
2013-08-06 Added full interface to motor_driver.
2013-08-06 Added I2C expander interface.
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2013-08-07 Added battery monitor to menu.
2013-08-08 I2C expander menu support.
2013-08-08 Added kill switch support.
2013-08-08 Added actual speed display to motor driver menu.
2013-08-08 Changed namespaces 'arm_driver' to 'arm' and 'motor_driver' to 'motor'.
2013-08-08 Updated names from MOTOR_X to X.
2013-08-08 Showing position in arm menu. Menu completed except kill switch.
2013-08-09 Corrected bridge voltage divider to match the resistor values.
    [bridge.brd, bridge.sch]
2013-08-10 Changed op-amp resistors values on the bridge schematic and general clean-up.
    [bridge.brd, bridge.sch]
2013-08-10 Replaced all _delay_ms with custom functions in separate file. The new delay function calls usbPoll().
    [main.cpp]
2013-08-10 Added interrupt routine to kill switch to hold down active state and modified the operation to open collector mode.
2013-08-10 Added protection from hang when i2c device is not available. Still testing version.
2013-08-11 Fixed wrong interrupt number.
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2013-08-11 Moved all protocol definitions in arm from defines to enums.
2013-08-11 Replaced defines with enums in motor driver interface.
    [main.cpp, motor_driver.cpp]
2013-08-11 Added kill switch support to menu.
2013-08-11 Updated waiting times and replaced custom waiting functions with _delay_ms in initialization functions.
    [main.cpp]
2013-08-12 Replaced NULL with nullptr.
    [menu.cpp]
2013-08-13 Added option to read buttons state without debouncing (no delay).
2013-08-18 arm and motor get.
2013-08-21 Added DataHolder class to hold requests. Changed arm, expander and motor classes to hold the pointer to Interface in order to use Implementation struct. Added some crazy reference initialization list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
2013-08-21 Implemented motor interface setters.
2013-08-22 Added arm interface to host.
2013-08-22 Added motor set and arm set to bridge.
2013-08-22 Changed bridge arm and motor get requests to support only one motor/joint at time.
2013-08-24 Reenabled menu in bridge, added some code in usb request and kill switch.
2013-08-24 Bridge support interrupt transfer to host.
2013-08-24 Removed RawCommunicator, interrupt transfer from device.
2013-08-26 I2C timer - stopping counting after successful receivement.
2013-08-27 Fixed missing watchdog reset in arm driver.
    [joint.cpp, main.cpp]
2013-08-28 Changed fusebits to start immadently after activation (without 65 ms delay).
2014-03-04 Rename 'bridge' project. Create board for new bridge.
    [bridge-old.brd, bridge-old.sch]
2014-03-06 bridge: Schematic beta version.
    [bridge.brd, bridge.sch]
2014-03-07 bridge: Update schematic positions and numbering.
    [bridge.brd, bridge.sch]
2014-03-10 bridge: board shape.
    [bridge.brd]
2014-03-13 bridge: Mock PCB ready.
    [bridge.brd, bridge.sch]
2014-03-13 bridge: Board ready beta.
    [bridge.brd, bridge.sch]
2014-03-13 bridge: Connect unused op-amp to the ground.
    [bridge.brd, bridge.sch]
2014-03-16 bridge: Update resistor values.
    [bridge.brd, bridge.sch]
2014-03-17 bridge: Adjust firmware to run on the new board.
    Makefile adjusted to program with AVRDoper.
2014-03-17 Add Arduino Pro Micro schematic.
2014-03-17 Fix common header references from .h to .hpp
    [joint.cpp, joint.h, main.cpp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]
2014-03-17 bridge: Update battery voltage factor.
2014-03-18 Change .h to .hpp in arm_driver and motor_driver.
2014-03-18 bridge: Add software reset when UP+DOWN buttons.
    [main.cpp]
2014-03-18 bridge: Add LED support.
2014-03-22 Send packet with the fixed size of 128 bytes. Fast.
    [main.cpp]
2014-03-22 bridge: Add timeout to USB communication. The menu is disabled during USB communication. When it's severed, device informs about it on the display and reenables menu.
2014-03-22 bridge: Add reset device command.
    [usb-commands.hpp]
2014-04-06 Updated .gitignore and change permissions.
    [encoder.brd, encoder.sch, encoder_se.brd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]
2014-05-08 server: Fix NetServer sendersMap accesses to be thread-safe.
2014-05-11 server: Fix some logging messagess and remove dummy direction setting for motor in interface.
2014-05-13 server: Add removing commands to I2C devices when kill switch enabled.
2014-05-14 server: Fix loosing settings for motor (double command).
2014-05-14 server: Same fix for arm.
2014-09-24 arm: Remove support of wrist.
2014-09-26 client: Add support of kill switch.
2014-09-26 server: Remove wirst and update killswitch.
2014-09-28 client: Add new camera updater support.
2014-09-28 client: Add switching between cameras.
2014-09-28 client: Add switching between RAW and HUD modes.
2014-09-29 client: Add disabling camera when error occurred.
2014-09-29 client: Move control from Timer task to SwingWorker.
2014-09-29 client: Add independent camera and control error handling.
2014-10-01 client: Add timeouts to sockets and fix error with hanging.
2014-10-03 client: Add calibration support.
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2014-10-09 szarkcam: Add thread naming and reading resolution from config.
2014-10-11 server: Fix sending calibration request.
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2014-10-14 server: Fix resetting calibration status when kill switch during calibration.
2014-10-14 arm: Fix random data after calibration.
    [joint.cpp]
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2014-10-18 server: Fix tests to compile.
    [main.cpp]
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2015-12-08 common: Fix tests to make them compile.
    [main.cpp]
2015-12-08 camera: Fix tests to make them compile. Add head camera classes.
    [main.cpp, main_framegrabber.cpp]
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2015-12-08 camera: Reformat CMakeLists.txt to create static library.
    * reformat all code
    * clean up headers and header guards
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2015-12-10 camera: Add FPS info and unoptimized OpenCV warning.
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2015-12-13 camera: Fix and refactor frame grabber in V4L.
    [main_framegrabber.cpp]
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2015-12-19 common: Add prevention from sending commands to arm during calibration.
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2015-12-20 camera: Add motor speed bars to head HUD.
2016-01-05 camera: Set better struct initialization. common: Add better test for shared interface.
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2016-02-07 Fix many of the warnings indicated by ultra-pedantic mode.
    [main_framegrabber.cpp]
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2016-04-10 camera: Add flip/rotate support.
2016-04-11 camera: Add video input support and dynamic flip.
    [main_gripper.cpp]
2016-04-11 camera: Add input support to Python camera viewer.
2016-04-13 camera: Fix NetworkServer types.
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

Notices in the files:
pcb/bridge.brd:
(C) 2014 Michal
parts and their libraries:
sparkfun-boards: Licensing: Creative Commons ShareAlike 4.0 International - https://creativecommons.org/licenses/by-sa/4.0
